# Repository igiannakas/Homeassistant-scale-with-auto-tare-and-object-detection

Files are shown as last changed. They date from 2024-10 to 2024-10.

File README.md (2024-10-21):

# Smart Scale with Object Detection and Auto-Tare
This is my over engineered Homeassitant integrated scale using an ESP32, esphome, proximity detection and weight (load) detection.

It implements a smart scale using an ESP32 microcontroller, designed to measure weight, detect when an object is placed on or removed from the scale and implement an auto-tare functionality to combat sensor drift over time. 

It features weight measurement, object detection using both weight change and a proximity sensor, auto-tare functionality, and visual feedback through an LED. The scale integrates with Home Assistant via ESPHome.

## Table of Contents
- [Features](#features)
- [Use Cases](#use-cases)
- [Required Components](#required-components)
- [Sourcing Components](#sourcing-components)
- [Hardware Setup](#hardware-setup)
- [Software Installation](#software-installation)
- [Calibration and Configuration](#calibration-and-configuration)
- [Additional Notes](#additional-notes)
- [License](#license)

## Features
- **Weight Measurement**: Measures the weight of objects using a load cell and HX711 amplifier.
- **Object Detection**: Detects when an object is added or removed based on weight change and confirms presence using a proximity sensor.
- **Auto-Tare Functionality**: Automatically tares the scale when no object is detected for a specified interval, ensuring consistent zero-point calibration.
- **Visual Feedback**: 
  - Green Light: Object is present on the scale.
  - Blinking Red Light: No object detected on the scale.
  - LED is exposed to Homeassistant for further control using automations
- **Configurable Thresholds**: Adjustable thresholds for object detection using weight changes and object proximity via Home Assistant.

## Use Cases
- Medication Adherence Monitoring
- Smart Kitchen Scale
- Pet Feeding Management

## Required Components
- ESP32 Development Board (Wemos D1 Mini32)
- Load Cell (eg. a 5kg load cell)
- HX711 Load Cell Amplifier Module
- APDS9960 Proximity, Light, RGB, and Gesture Sensor
- Neopixel (WS2811) LED (1 LED)
- Jumper Wires
- Power Supply (5V USB)

Optional: Enclosure or housing for the scale. An enclosure STL, STEP and F3D file is included in the project files.

## Sourcing Components
- ESP32 Development Board
- Load Cell and HX711 Amplifier
- APDS9960 Proximity Sensor
- Neopixel (WS2811) LED

## Hardware Setup
### Wiring Diagram
- **HX711 Load Cell Amplifier**: 
  - DOUT to ESP32 GPIO 27
  - CLK to ESP32 GPIO 25
  - Connect the load cell as per module instructions.
  
- **APDS9960 Proximity Sensor (I2C Connection)**:
  - SDA to ESP32 GPIO 18
  - SCL to ESP32 GPIO 19
  - VCC to 3.3V
  - GND to GND
  
- **Neopixel LED**:
  - Data pin to ESP32 GPIO 16
  - VCC to 5V
  - GND to GND

- **ESP32 Power Supply**: Use a 5V USB power source

## Software Installation
### Prerequisites
- Install [ESPHome](https://esphome.io) on your computer or Home Assistant.

### Steps
1. Download the ESPHome configuration file.
2. Modify the Wi-Fi credentials and GPIO pin assignments if needed.
3. Compile and upload the firmware to your ESP32 board.
4. Add the device to Home Assistant if using it.

## Calibration and Configuration

### Exposed entities in Home Assistant


### Load Cell Calibration
- Place known weights on the scale and record raw values.
- Adjust calibration data points in the `hx711` sensor configuration.
- Re-upload the updated configuration.

### Threshold Configuration
- Adjust object detection thresholds via Home Assistant.
- Set switches for auto-tare and proximity confirmation as needed.

## Additional Notes
### Understanding the Logic
- Object detection is based on weight change and proximity confirmation. The initial object detection is done based on rapid weight change, when an object is lifted or placed on the scale. The rate of weight change is controlled by the Add and Remove object threshold values.
- If enabled, the proximity sensor is used to confirm whether an object is trully removed from the scale. After the configured delay, it checks the proximity sensor reading against the proximity threshold and if below, it assumes there is no object present on the scale
- If enabled, it can auto-tare the device when the proximity sensor reads below the proximity threshold after the configured time has passed. This is usefull for automatic setting of the zero-point calibration when the scale is empty, as seen by the proximity sensor. 

### Visual Feedback
- Green Light: Object detected on the scale
- Blinking Red Light: No object detected on the scale
- LED is exposed to Homeassistant for control via automations

### Troubleshooting Tips
- Inconsistent readings: Ensure stable mounting of the load cell.
- Proximity sensor not detecting: Verify I2C connections.
- LED issues: Check Neopixel wiring and power supply.

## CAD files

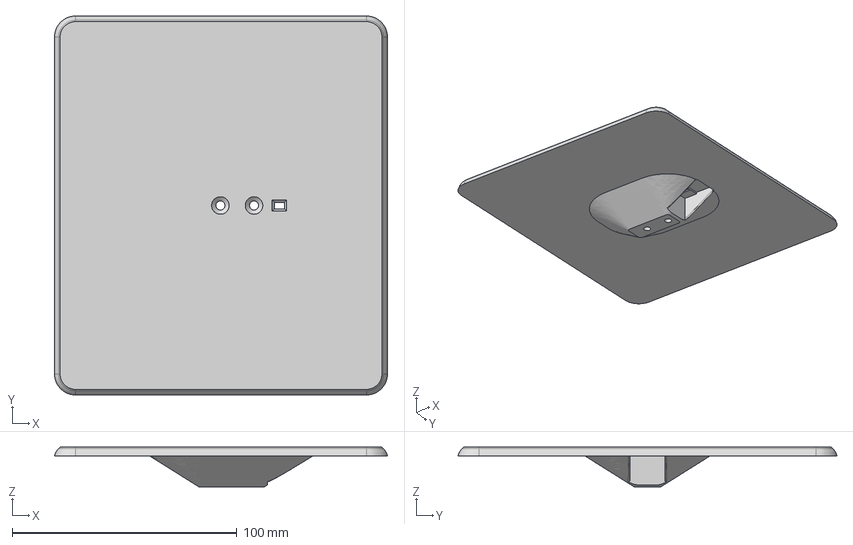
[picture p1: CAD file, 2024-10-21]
Scale Enclosure Files/Scale Platform.step
148.4 x 168.8 x 17.8 mm

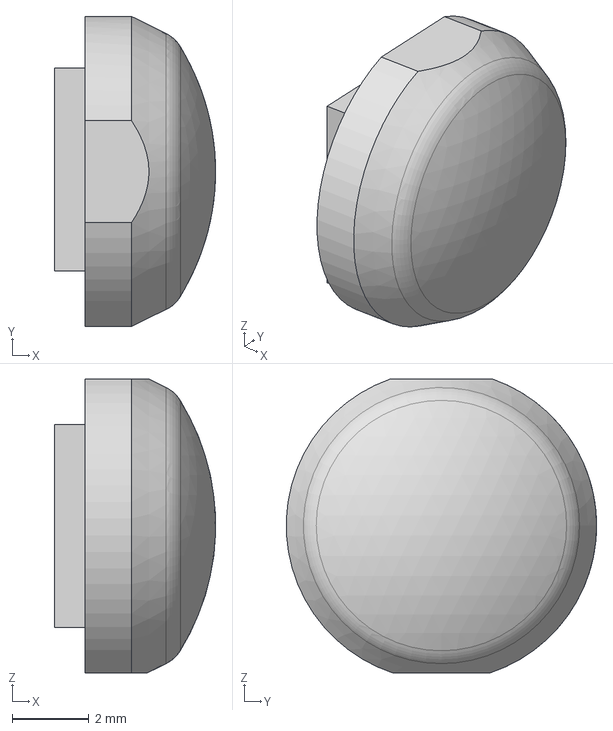
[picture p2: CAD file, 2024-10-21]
Scale Enclosure Files/Scale Body - LED lens.step
4.19 x 8.07 x 7.65 mm

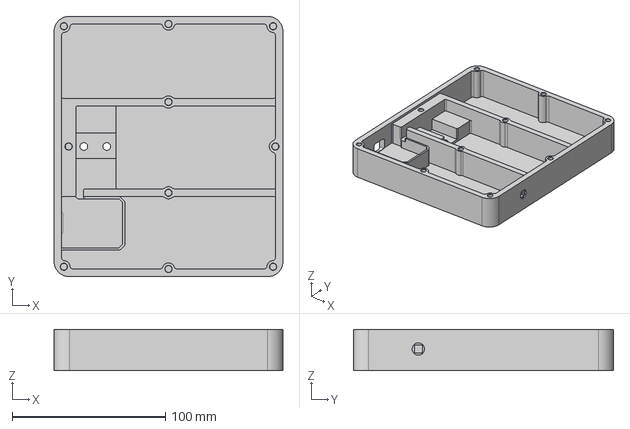
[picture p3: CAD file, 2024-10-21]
Scale Enclosure Files/Scale Body.step
149.6 x 170.0 x 27.0 mm

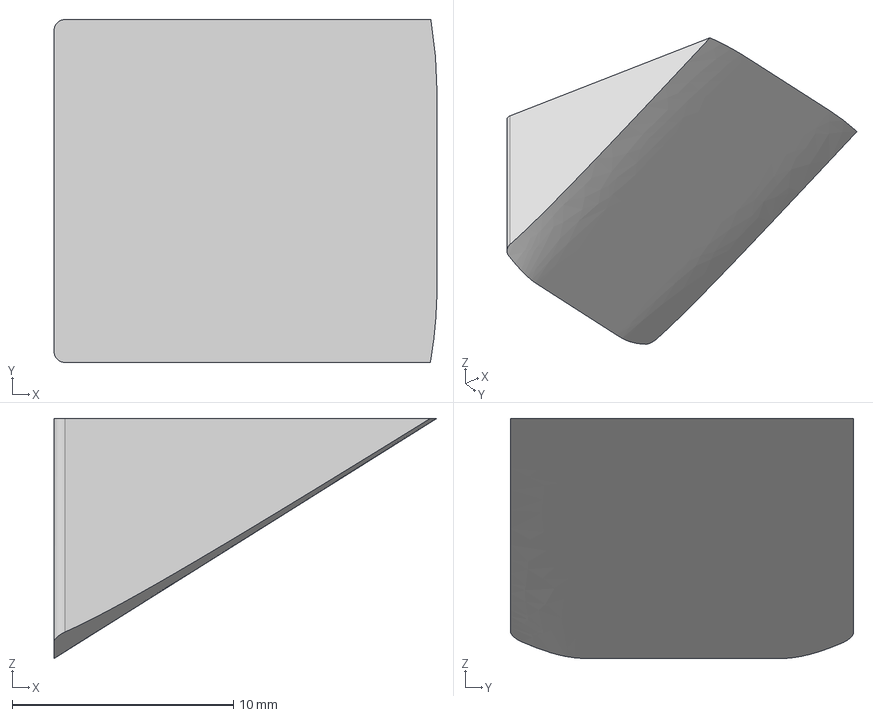
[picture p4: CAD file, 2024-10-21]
Scale Enclosure Files/Scale Platform - Sensor cap.step
17.3 x 15.5 x 10.9 mm

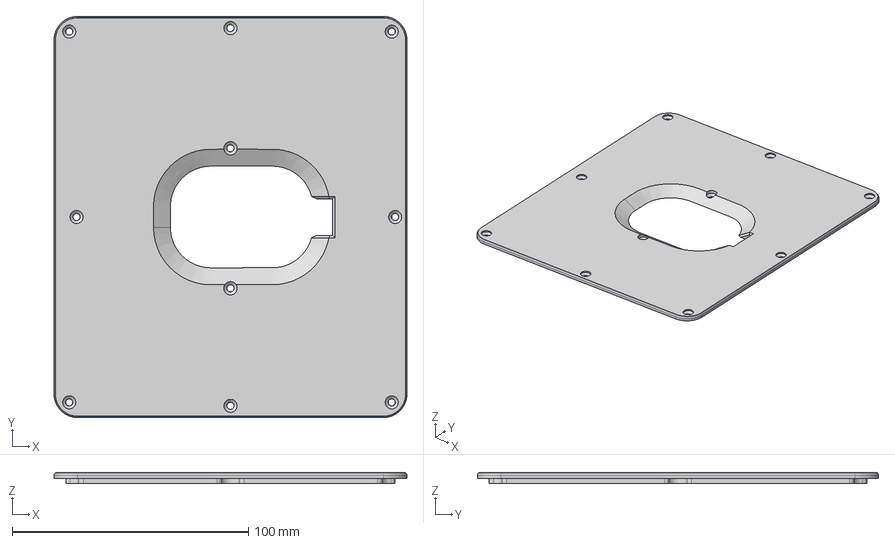
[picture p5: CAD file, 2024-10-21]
Scale Enclosure Files/Scale Body - Lid.step
149.6 x 170.0 x 4.50 mm

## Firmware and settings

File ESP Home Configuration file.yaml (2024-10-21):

substitutions:  
  ssid1: <<SSID1>>
  wifi_password1: <<SSID1 Password>>

  ssid2: <<SSID2>>
  wifi_password2: <<SSID2 Password>>
  log_level: "INFO"

  # Strain gauge sensor connections
  dout_pin: '27'
  clk_pin: '25'
  
  # Neopixel data pin connection
  neopixel_pin: '16'

  # Timing variables
  update_interval_ms: "400ms" # Scale weight reading update interval
  proximity_check_delay: '5s' # How long after an object removal due to weight change 
                              # should the proximity sensor reading be used to cross check for object present on the scale
  proximity_check_scheduled_interval: '40s' # How often to schedule periodic proximity check to validate object still present on the scale
  auto_tare_interval: '30s' # Every how often should auto tare take place when no object is present
  tare_time_window: '2s' # Over how many seconds should weight measurements be taken to calculate tare offset
  object_presense_debounce: "800ms" #debounce timeframe - set to 2x or more of the update interval

esphome:
  name: auto-tare-scale

esp32:
  board: wemos_d1_mini32
  framework:
    type: arduino

api:
  password: ""

ota:
  - platform: esphome
    password: ""

wifi:
  networks:
    - ssid: "${ssid1}"
      password: "${wifi_password1}"
    - ssid: "${ssid2}"
      password: "${wifi_password2}"

  # Enable fallback hotspot (captive portal) in case Wi-Fi connection fails
  ap:
    ssid: "Scale"
    password: "${wifi_password1}"

captive_portal:

web_server:
  port: 80
  version: 2
  include_internal: true

http_request:
  verify_ssl: false

# Enable logging
logger:
  level: ${log_level}

i2c:
  sda: 18
  scl: 19
  scan: true

apds9960:
  address: 0x39
  update_interval: 500ms  # Faster updates for responsive detection

light:
  - platform: neopixelbus
    type: GRB
    variant: WS2811
    pin: ${neopixel_pin}
    num_leds: 1
    name: "Light"
    id: light_id
    effects:
      - strobe:
          name: "Blinking Red"
          colors:
            - state: True
              brightness: 100%
              red: 100%
              green: 0%
              blue: 0%
              duration: 1200ms
              transition_length: 1000ms
            - state: False
              duration: 1000ms
              transition_length: 1000ms
      - strobe:
          name: "Blinking Green"
          colors:
            - state: True
              brightness: 100%
              red: 0%
              green: 100%
              blue: 0%
              duration: 1200ms
              transition_length: 1000ms
            - state: False
              duration: 1000ms
              transition_length: 1000ms
      - strobe:
          name: "Rapid white flashing"
          colors:
            - state: True
              brightness: 100%
              red: 100%
              green: 100%
              blue: 100%
              duration: 100ms
              transition_length: 100ms
            - state: False
              duration: 100ms
              transition_length: 100ms

# Expose Thresholds to Home Assistant
number:
  - platform: template
    name: "Add Object Threshold"
    id: add_object_threshold_number
    min_value: 0.0
    max_value: 100.0
    initial_value: 20
    step: 0.1
    unit_of_measurement: "g/s"
    optimistic: true
    restore_value: true
    mode: box
    entity_category: config

  - platform: template
    name: "Remove Object Threshold"
    id: remove_object_threshold_number
    min_value: -100.0
    max_value: 0.0
    initial_value: -20
    step: 0.1
    unit_of_measurement: "g/s"
    optimistic: true
    restore_value: true
    mode: box
    entity_category: config

  - platform: template
    name: "Proximity Threshold"
    id: proximity_threshold
    min_value: 0.0
    max_value: 255.0
    initial_value: 10  # Set a reasonable default
    step: 1.0
    unit_of_measurement: ""
    optimistic: true
    restore_value: true
    mode: box
    entity_category: config
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
